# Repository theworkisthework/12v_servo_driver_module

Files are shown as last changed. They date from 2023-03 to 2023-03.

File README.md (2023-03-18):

12v (to 5v) Servo driver module

Allows connecting a standard 5v servo directly to a 12v supply.
Intended for the plotter controller board and avoids having to change the supply voltage jumper on the main board.

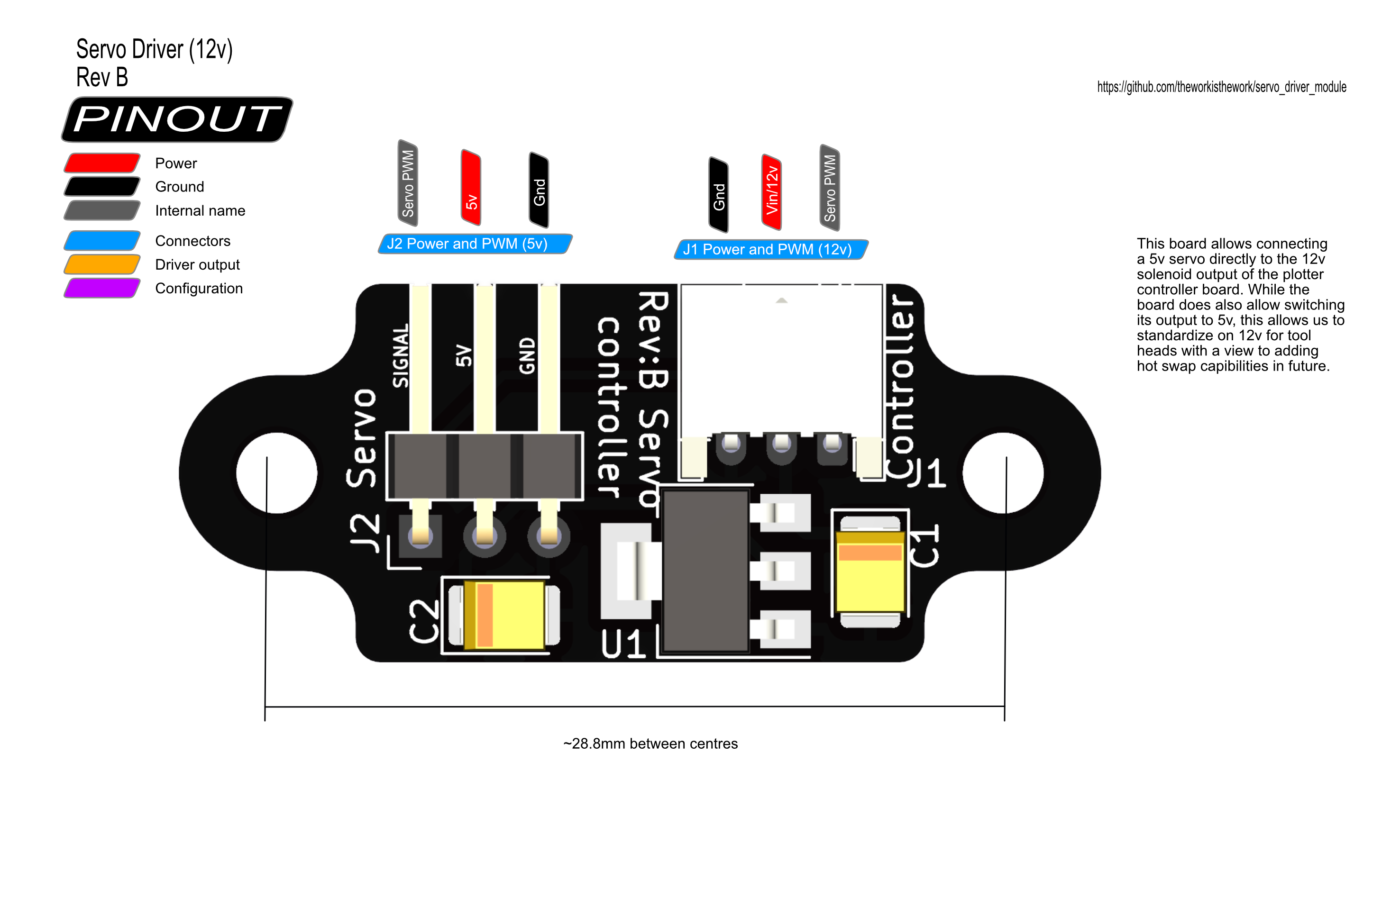
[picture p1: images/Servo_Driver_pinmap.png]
Pinmap


The thinking is if we standardize on 12v that will allow more scope for different tool heads.

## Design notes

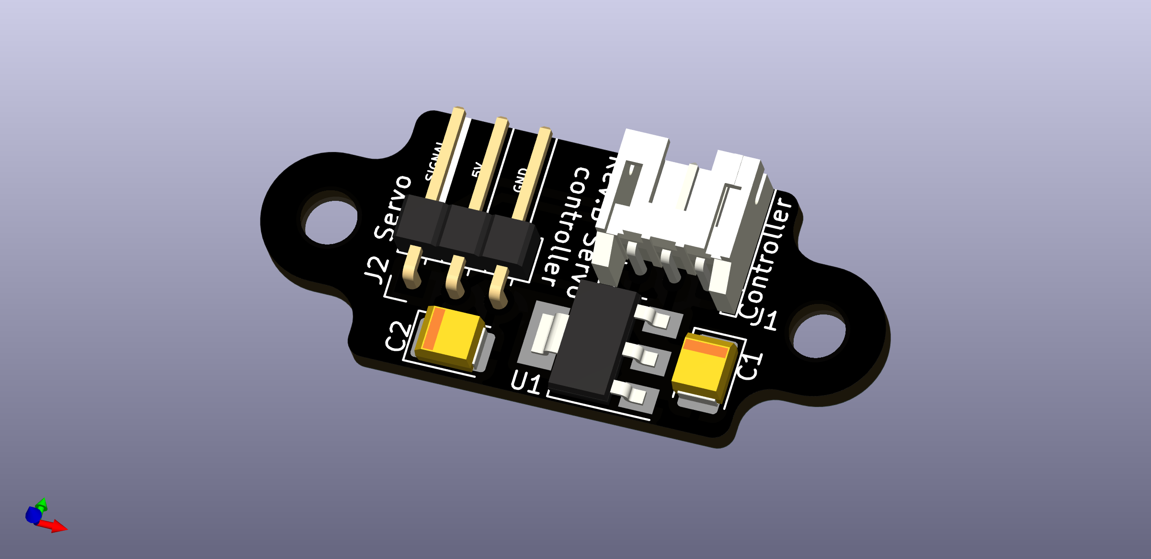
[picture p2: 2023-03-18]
images/12v_servo_driver.png

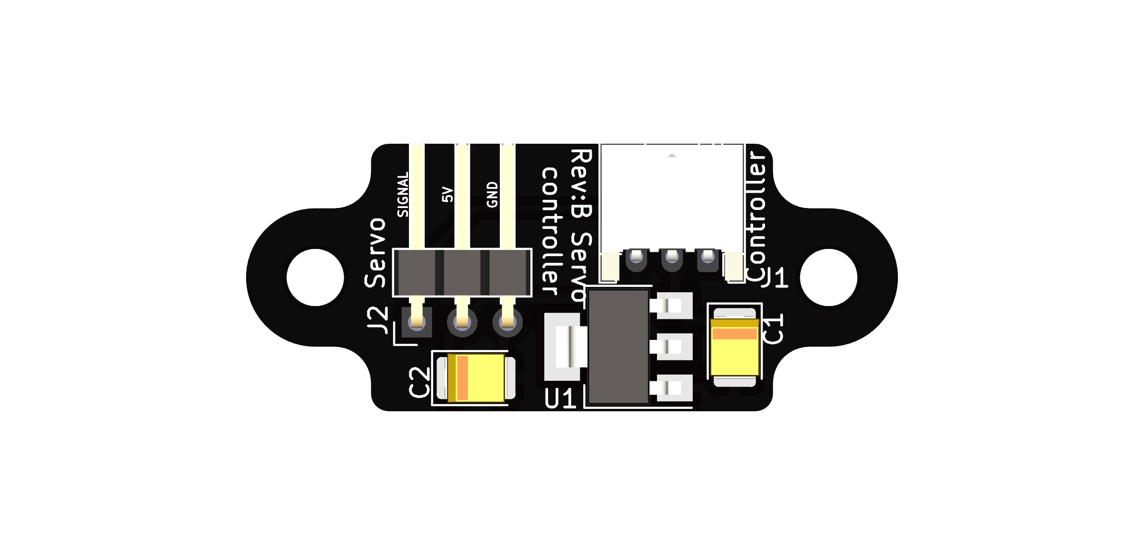
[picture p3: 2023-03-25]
images/12v_servo_driver_top.png

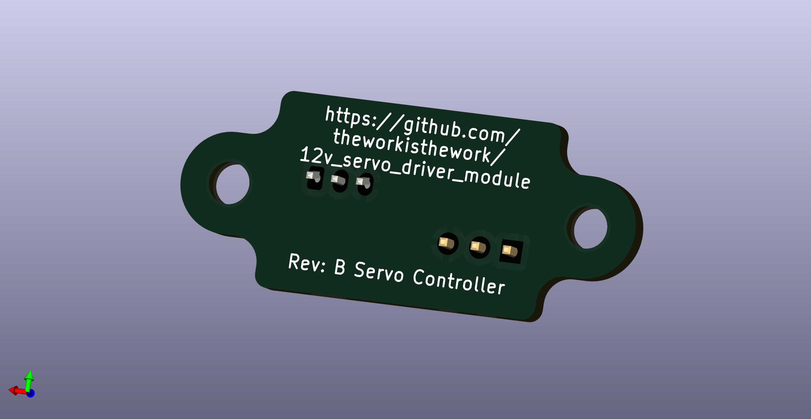
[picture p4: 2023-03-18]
images/12v_servo_driver_back.png

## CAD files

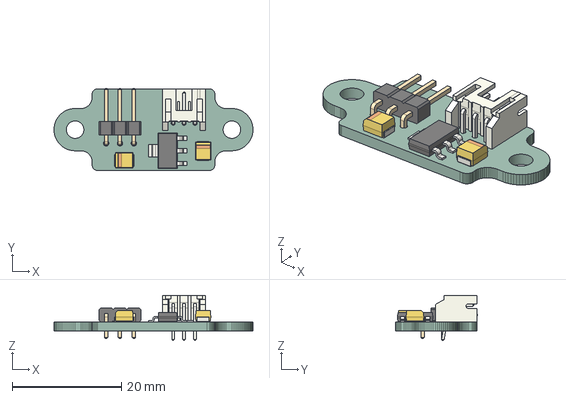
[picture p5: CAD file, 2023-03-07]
12v_servo_driver.step
36.4 x 15.0 x 8.25 mm
PCB

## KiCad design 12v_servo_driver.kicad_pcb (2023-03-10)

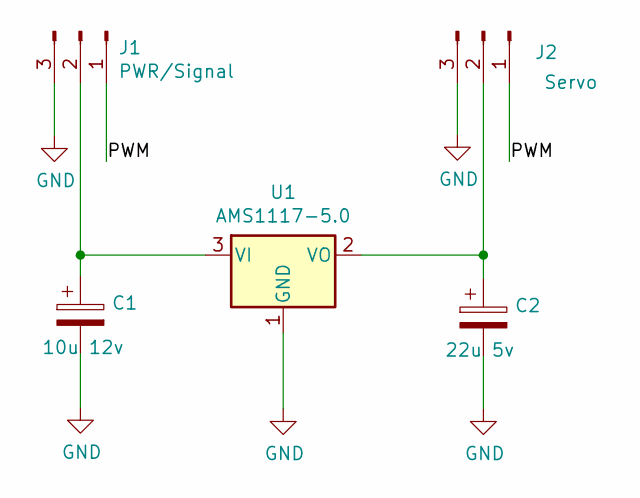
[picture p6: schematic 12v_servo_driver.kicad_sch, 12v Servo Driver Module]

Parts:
C1: 10u 12v; CP_EIA-3528-21_Kemet-B; LCSC C117028
C2: 22u 5v; CP_EIA-3528-21_Kemet-B; LCSC C2798070
J1: PWR/Signal; JST_PH_S3B-PH-K_1x03_P2.00mm_Horizontal; LCSC C146083
J2: Servo; PinHeader_1x03_P2.54mm_Horizontal; LCSC C8886
U1: AMS1117-5.0; SOT-223; LCSC C347223

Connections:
/PWM: J1.1, J2.1
GND: C1.2, C2.2, J1.3, J2.3, U1.1 (GND)
unnamed: C1.1, J1.2, U1.3 (VI)
unnamed: C2.1, J2.2, U1.2 (VO)

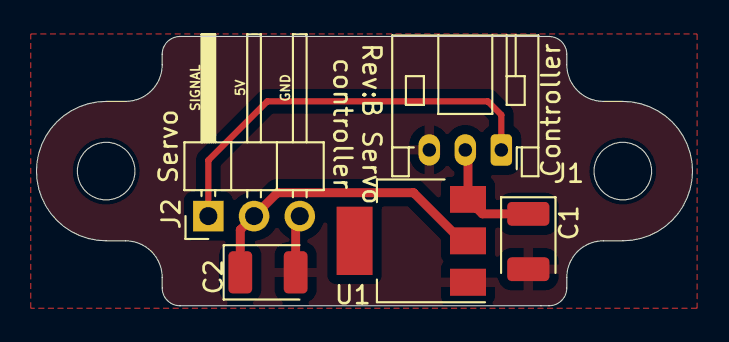
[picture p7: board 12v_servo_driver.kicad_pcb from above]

Board: 2 copper layers, 36.4 x 15.0 mm, 5 parts (0 on the bottom side), 4 nets.

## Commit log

2022-09-19 Update page info and add gerber
    [12v_servo_driver-B_Cu.gbl, 12v_servo_driver-B_Mask.gbs, 12v_servo_driver-B_Paste.gbp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]
2023-03-03 Add pinout documentation
    [12v_servo_driver.kicad_pcb]
2023-03-06 Add step model
    [12v_servo_driver.step]
2023-03-06 Update project for kicad 7 and add doc
2023-03-07 RevB
    Right angle connectors on both servo and controller connectors.
    Both connectors on same side of the board.
    [12v_servo_driver.kicad_pcb, 12v_servo_driver.kicad_sch, 12v_servo_driver.step]
2023-03-07 Make power tracks 0.75mm rather than 0.5mm
    [12v_servo_driver.kicad_pcb]
2023-03-10 Update gerber for RevB
    [12v_servo_driver-B_Cu.gbl, 12v_servo_driver-B_Mask.gbs, 12v_servo_driver-B_Paste.gbp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]
2023-03-18 Update board version in pinmap
2023-03-24 Update pin map to correctly show individual pins
